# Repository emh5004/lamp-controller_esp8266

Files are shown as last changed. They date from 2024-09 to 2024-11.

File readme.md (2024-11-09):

# Lamp Controller
esp 8266-based replacement for a bad microcontroller on kiddo's amazon bedside reading lamp.
Original featured soft switches for on/off and color temp. something went bad and wouldn't operate correctly.
Lamp is just two arrays of bright and warm white leds behind a diffuser on a gooseneck type thing. They share a common anode - pwm on a NPN transistor pretty simply controls light levels on each of the two channels.
## Improvements over the original
Kiddo loves reading, but can't be trusted not to turn back on late at night!
Web based panel means bright/warm channel PWM is controlled from phone. single physical soft power button for on/off can be defeated by setting the bright and warm channels to 0. Added a timer that counts down from a number of presets and switches off (but leaves PWM to settings stored in memory.). If necessary, future commit may bake in more stringent scheduling or timed setting PWM to zero rather than flipping the soft "off" switch.
## Implementing this
Opted for a raw esp-12 module for space/size advantages. In addition to that, needed a 3.3v regulator, and some basic resistors and transistors, and one push button. Used the original lamp's USB connector, wire leads, and strain relief boots that fit nicely in a replacement plastic enclosure.
### wiring
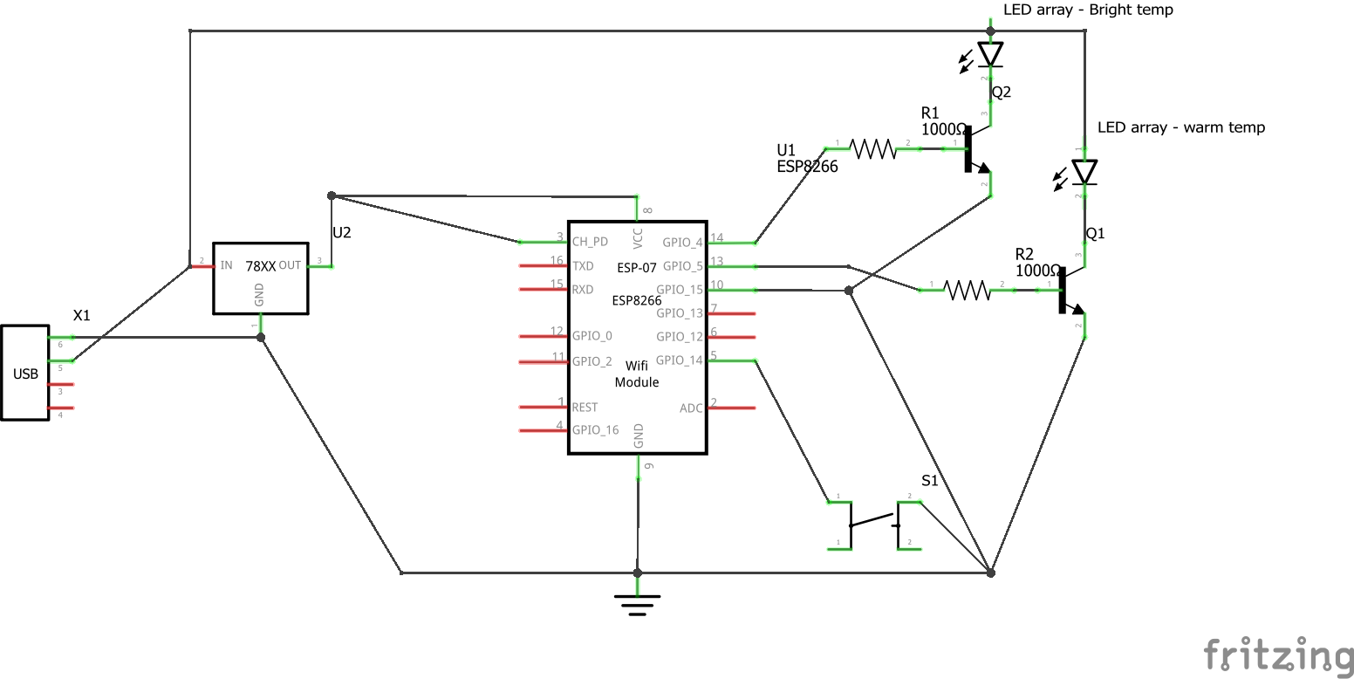
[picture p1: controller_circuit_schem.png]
Fritzing image showing the wiring Controller Circuit Diagram

Fritzing file in this repo.
### main.py
main.py file depends on micropython running on the esp module. main.py relies on micropython's default functionality to remember and conenct to the most recent wifi network. If making with a raw module, some kind of REPL/serial console action will be required to get the chip up and running.
main.py serves up the index.html file when it recieves a GET request to the root endpoint and contains no url parameters.
### api-ish functionality
main.py will act differently if the GET request to / includes parameters with key/values in the typical ?key=value&another-key=another-value URL syntax:
 - `on`
    - purpose: turn lamp on/off, preserving PWM values in memory
    - acceptable values: `0` for off or `1` for on
 - `gpio4`
     - purpose: set the PWM duty cycle for gpio 4
    - values: integer from `0` through `1023`
 - `gpio5`
    - purpose: set the PWM duty cycle for gpio 5
    - values: integer from `0` through `1023`
 - `timeout`
    - purpose: set lamp to shut off (preserving PWM values in memory) in any number of minutes in the future.
    - values: integer
any GET to / with one or more agument(s) will return with a json structure of the state of the lamp.
If you just want the json state without changing any parameters, that can also be retrieved by making a GET request to the `/state` endpoint.

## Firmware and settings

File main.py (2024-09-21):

import uasyncio as asyncio
import usocket as socket
import machine
import time
import ntptime
ntptime.settime()
rtc = machine.RTC()


# GPIO pin assignments
GPIO_2 = machine.Pin(2, machine.Pin.OUT)
GPIO_4 = machine.PWM(machine.Pin(4))
GPIO_5 = machine.PWM(machine.Pin(5))
GPIO_14 = machine.Pin(14,machine.Pin.IN,machine.Pin.PULL_UP)
GPIO_4.freq(1000)
GPIO_5.freq(1000)


# HTTP server configuration
ADDR = ('0.0.0.0', 80)

#boolean of whether light is on or off
global ONOFF
ONOFF = 0

#hold pwm vals for the two gpios
global GPIO_4_STATUS
GPIO_4_STATUS = 0
global GPIO_5_STATUS
GPIO_5_STATUS = 0

#target time offset from system clock for shutdown timer
global OFFTARGET
OFFTARGET = None

def handle_request(request):
    global ONOFF
    global GPIO_4_STATUS
    global GPIO_5_STATUS
    global OFFTARGET
    global rtc
    if request.startswith('GET /?'):
        try:
            query = request.split(' ')[1].split('?')[1]
            params = query.split('&')
            for param in params:
                key, value = param.split('=')
                if key == 'on':
                    ONOFF = 0
                    if int(value) == 1:
                        ONOFF = 1
                if key == 'gpio4':
                    GPIO_4_STATUS = int(value)
                if key == 'gpio5':
                    GPIO_5_STATUS = int(value)
                if key == 'shutdown':
                    if value == "":
                        OFFTARGET = None
                    else:
                        OFFTARGET = time.mktime(rtc.datetime()) + (int(value))
            if ONOFF == 1:
                print("light on!")
                GPIO_4.duty(GPIO_4_STATUS)
                print(GPIO_4_STATUS)
                GPIO_5.duty(GPIO_5_STATUS)
                print(GPIO_5_STATUS)
                print("offtarget is: {}".format(OFFTARGET))
            else:
                print("light off")
                GPIO_4.duty(0)
                GPIO_5.duty(0)
            ot = OFFTARGET
            if OFFTARGET == None:
                ot = "\"\""
            return '{{"on":{},"4":{},"5":{},"localTime":{},"offTarget":{}}}'.format(ONOFF,GPIO_4_STATUS,GPIO_5_STATUS,time.mktime(rtc.datetime()),ot)
        except Exception as e:
            print('Error handling GET request:', e)
            return 'Error handling GET request'
    elif request.startswith('GET /state'):
        try:
            ot = OFFTARGET
            if OFFTARGET == None:
                ot = "\"\""
            return '{{"on":{},"4":{},"5":{},"localTime":{},"offTarget":{}}}'.format(ONOFF,GPIO_4_STATUS,GPIO_5_STATUS,time.mktime(rtc.datetime()),ot)
        except Exception as e:
            print('Error handling GET request:', e)
            return 'Error handling GET request'
    else:
        try:
            with open('index.html', 'r') as f:
                html_response = f.read()
                return html_response
        except Exception as e:
            print('Error reading HTML file:', e)
            return 'Error reading HTML file'

async def handle_client(reader, writer):
    print("client connected")
    data = await reader.read(1024)
    #print(data)
    request = data.decode('utf-8')
    response = handle_request(request)
    #print(response)
    writer.write(response.encode('utf-8'))
    await writer.drain()
    await writer.wait_closed()
    print("disconnected")

async def main():
    asyncio.create_task(checkTimer())
    asyncio.create_task(pollButton())
    while True:
        print('Setting up webserver...')
        server = await asyncio.start_server(handle_client, ADDR[0], ADDR[1])
        async with server:
            while True: 
                await asyncio.sleep(300)

async def pollButton():
    global ONOFF
    while True:
        while GPIO_14.value():
            await asyncio.sleep(.2)
        if ONOFF:
            ONOFF = 0
            GPIO_4.duty(0)
            GPIO_5.duty(0)
        else:
            ONOFF = 1
            GPIO_4.duty(GPIO_4_STATUS)
            GPIO_5.duty(GPIO_5_STATUS)
        await asyncio.sleep(1)

async def checkTimer():
    global OFFTARGET
    global rtc
    global ONOFF
    while True:
        await asyncio.sleep(15)
        print("checking timer...")
        if OFFTARGET != None:
            if OFFTARGET < time.mktime(rtc.datetime()):
                # Timer expired, set GPIO duty cycles to 0
                ONOFF = 0
                GPIO_4.duty(0)
                GPIO_5.duty(0)
                OFFTARGET = None

# Run the main coroutine
                
asyncio.run(main())

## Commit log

2024-08-21 first commit of functionality with schematic files
    [controller circuit.fzz]
2024-09-21 added code to handle both web and physical power soft switches, including css toggle switch styling
2024-11-09 updated schematic and documentation to match latest functionality with soft physical button
    [controller circuit.fzz]
